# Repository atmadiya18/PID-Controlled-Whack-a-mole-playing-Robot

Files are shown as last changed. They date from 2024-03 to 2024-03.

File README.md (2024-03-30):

**PID Controlled Whack-a-mole playing robot** [_Jan 2022 - May2021_]
- Designed a "Whack-a-Mole" robot utilizing a PID control system for enhanced gameplay precision and interaction. Emphasized real-time responsiveness and dynamic strike        
  capabilities through meticulously calibrated control algorithms.
- Comprehensive Sensor Suite: Integrated a diverse array of sensors, including ultrasonic for distance measurement, an IMU for orientation and movement tracking, a line 
  follower sensor for precise path navigation, and an RGB color sensor for advanced target identification based on color differentiation.
- Engineered robot's mechanical structure using CATIA to optimize agility and efficiency. Employed servo motors for actuation, achieving rapid and precise movements, essential 
  for striking targets with high accuracy.
- Orchestrated complex operational logic using Arduino, effectively synthesizing sensor inputs with mechanical actions. Applied PID algorithms to fine-tune the robot's 
  movements and strikes, significantly reducing reaction times and increasing strike precision.
- Through strategic adjustments to the PID parameters and the integration of a holistic sensor approach, realized a 70% improvement in the robot's response time and a 45% 
  increase in accuracy. Demonstrated the robot's superior performance in adapting to game dynamics.
Project Impact and Innovation: The project exemplified the convergence of robotics, sensor technology, and control systems in creating interactive entertainment solutions. Set new benchmarks in automated game play, showcasing the potential for robotics in engaging and complex environments.

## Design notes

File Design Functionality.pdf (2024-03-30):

# DESIGN REQUIREMENTS AND CONSTRAINTS

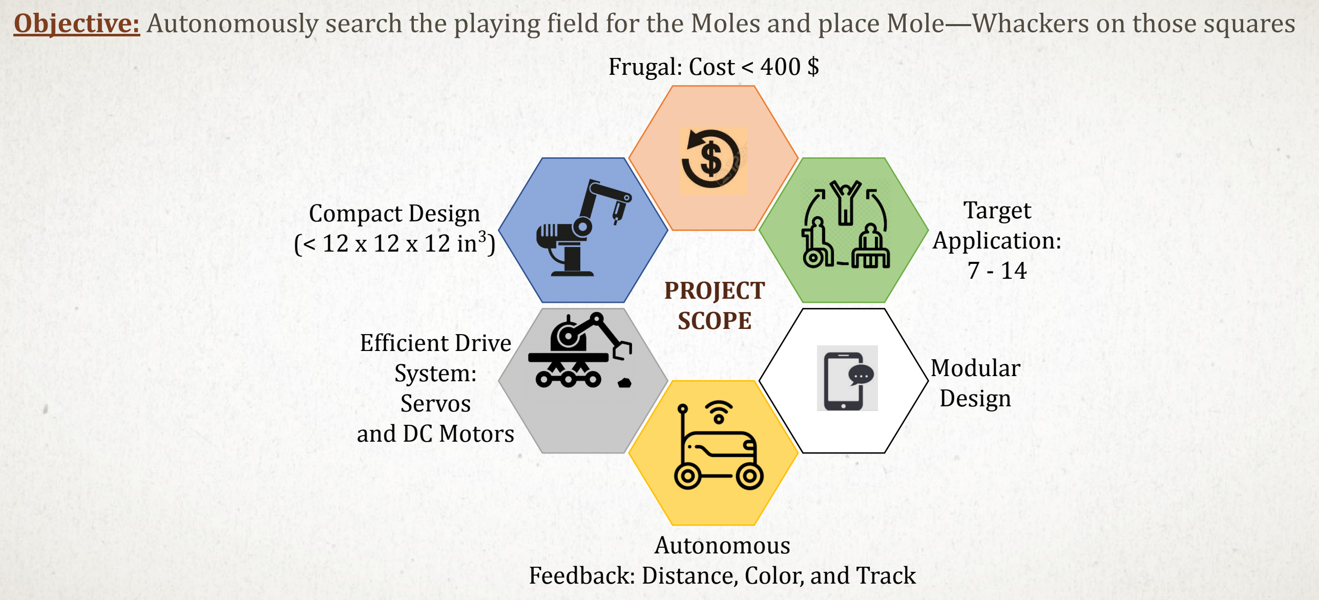
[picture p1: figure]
Frugal: Cost < 400 $; Target Application: 7 - 14; Modular Design; Compact Design (< 12 x 12 x 12 in³; Efficient Drive System: Servos and DC Motors; Autonomous Feedback: Distance, Color, and Track; PROJECT SCOPE

Objective: Autonomously search the playing field for the Moles and place Mole—Whackers on those squares

# DESIGN FUNCTIONALITY

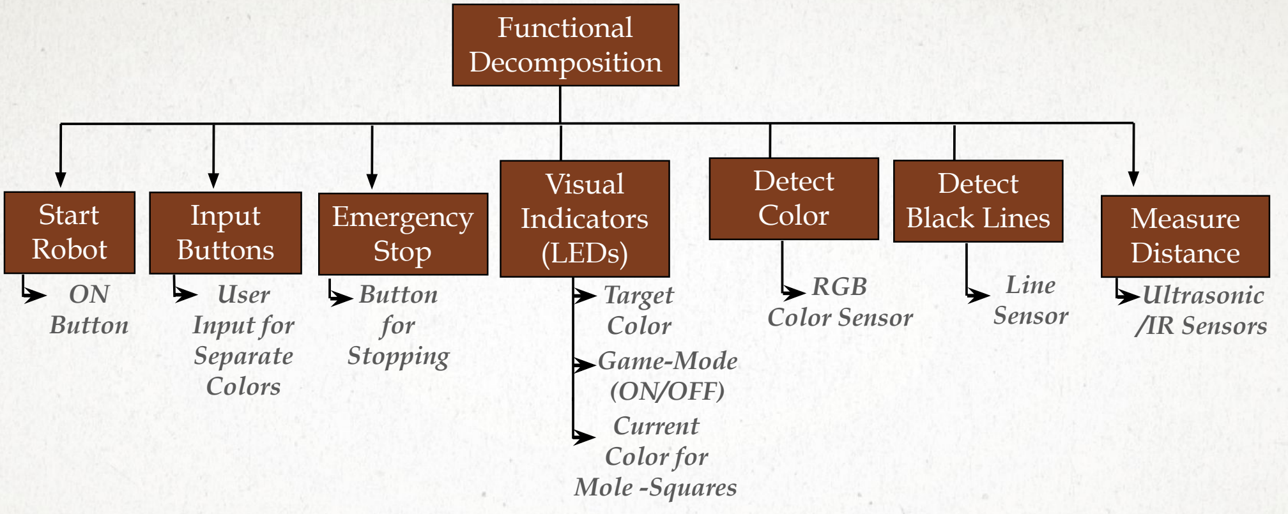
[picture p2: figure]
Start Robot; Measure Distance; Input Buttons; Emergency Stop; ON Button; User Input for Separate Colors; Button for Stopping; Ultrasonic /IR Sensors; Target Color; Functional Decomposition; Visual Indicators (LEDs); Game-Mode (ON/OFF) Current Color for Mole -Squares; RGB Color Sensor; Detect Color; Line Sensor; Detect Black Lines

# SYSTEMS ENGINEERING LAYOUT

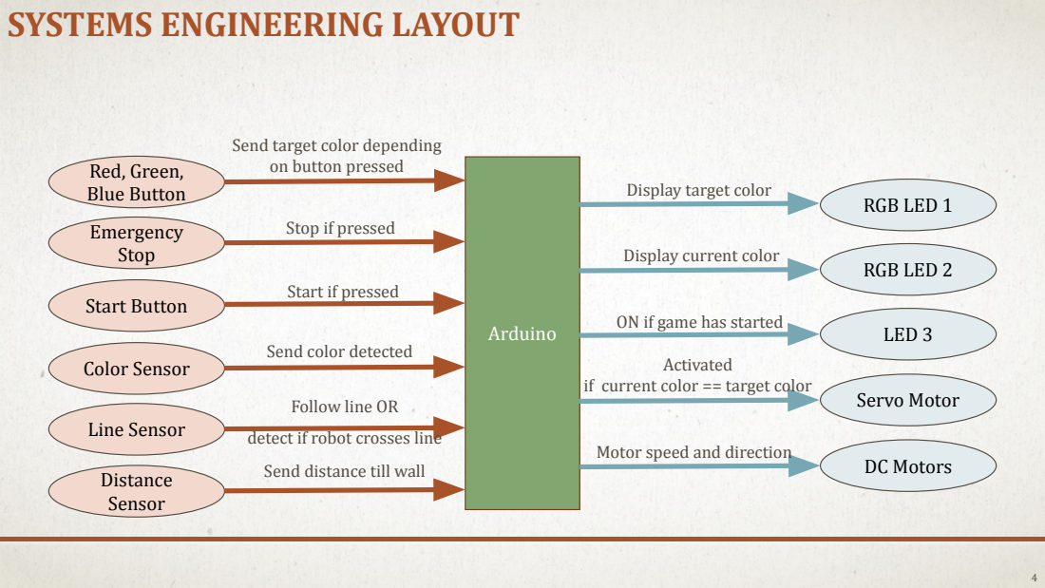
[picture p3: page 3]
Arduino; Red, Green, Blue Button; Emergency Stop; Start Button; Color Sensor; Line Sensor; RGB LED 1; RGB LED 2; LED 3; Servo Motor; DC Motors; Distance Sensor; Activated

Send target color depending
on button pressed

Display target color

Stop if pressed

Display current color

Start if pressed

ON if game has started

Send color detected

if current color == target color

Follow line OR
detect if robot crosses line

Motor speed and direction

Send distance till wall

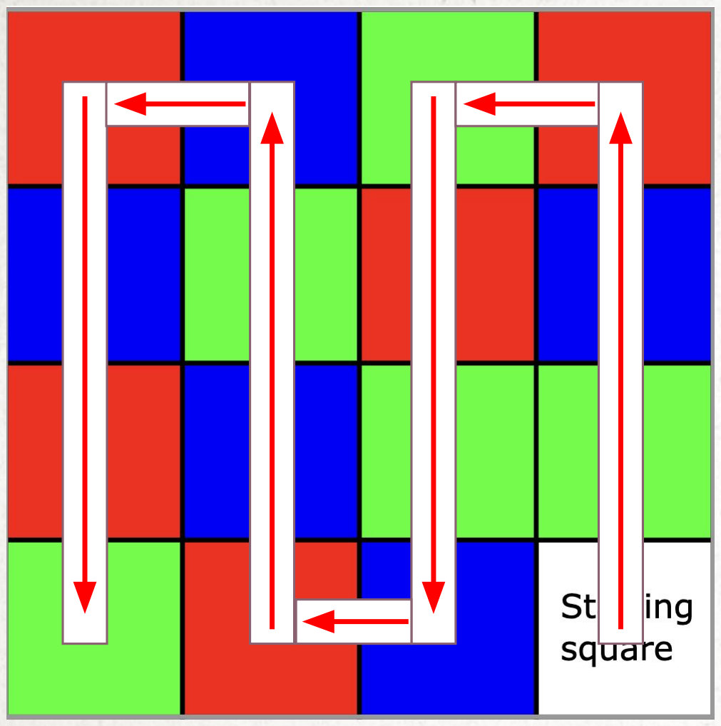
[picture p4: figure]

❑ Every Square Method
Robot follows the path given by the arrows to traverse every square
Based on the square under the robot: ball is dropped
This method might be the easiest to implement but could be slower

## STRATEGY: EVERY SQUARE METHOD

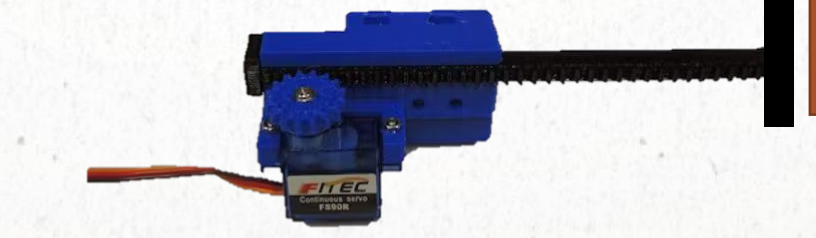
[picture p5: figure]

## STRATEGY: LINE FOLLOWER METHOD

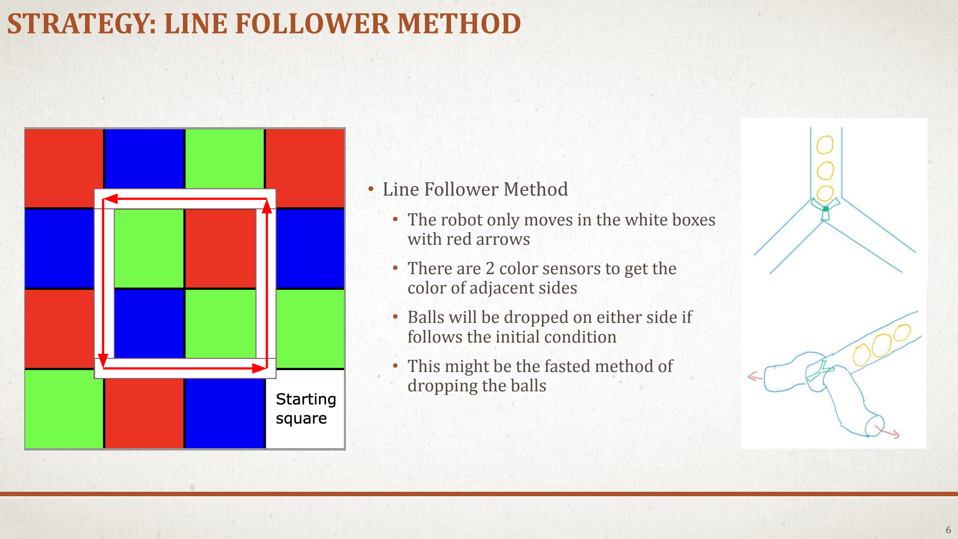
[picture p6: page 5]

- Line Follower Method
- The robot only moves in the white boxes with red arrows
- There are 2 color sensors to get the color of adjacent sides
- Balls will be dropped on either side if follows the initial condition
- This might be the fasted method of dropping the balls

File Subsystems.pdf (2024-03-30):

## MOVEMENT OF THE CHASSIS

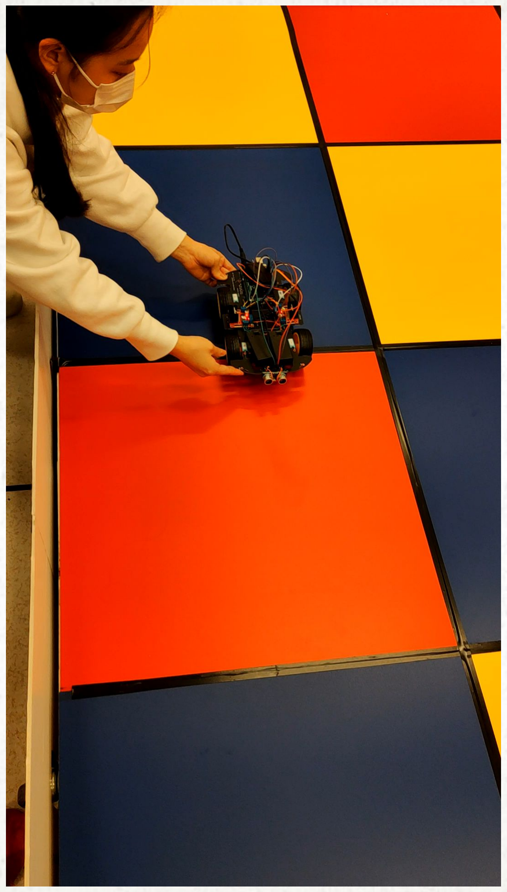
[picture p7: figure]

## MOLE-WHACKER DEPLOYMENT

- Servo motor horn attached to a structure with slots for mole-whacker to be deployed
- Range of motion of the servo horn (< 180 degrees) to deploy the mole-whacker
- Need for designing the mole-whacker deployer and servomotor to the chassis

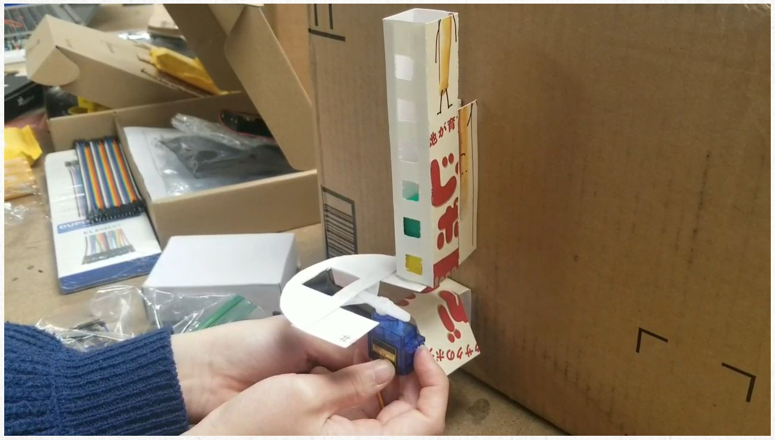
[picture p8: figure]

## SENSOR MODALITIES: ULTRASONIC SENSOR

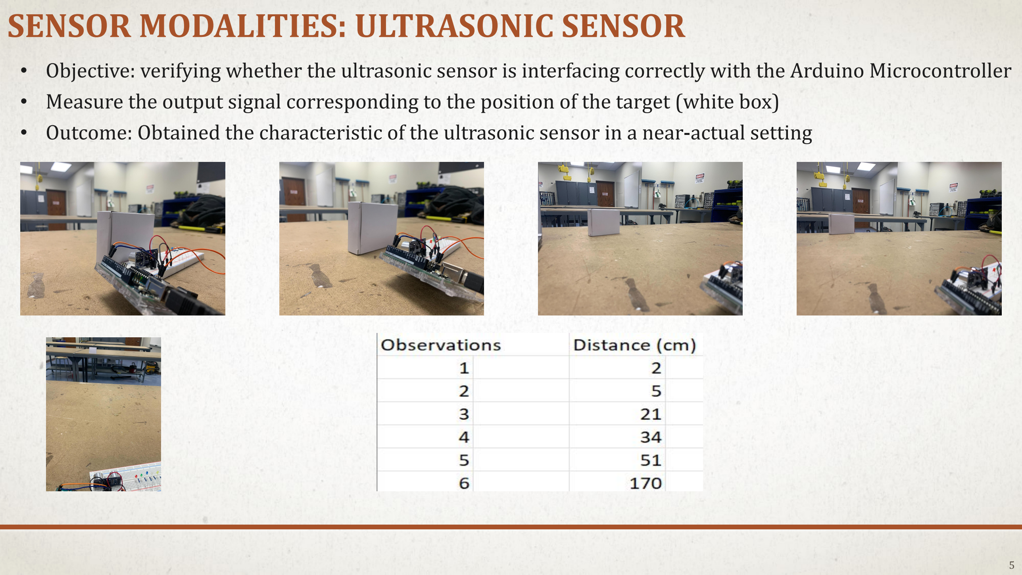
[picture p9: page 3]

- Objective: verifying whether the ultrasonic sensor is interfacing correctly with the Arduino Microcontroller
- Measure the output signal corresponding to the position of the target (white box)
- Outcome: Obtained the characteristic of the ultrasonic sensor in a near-actual setting

## SENSOR MODALITIES: LINE FOLLOWER

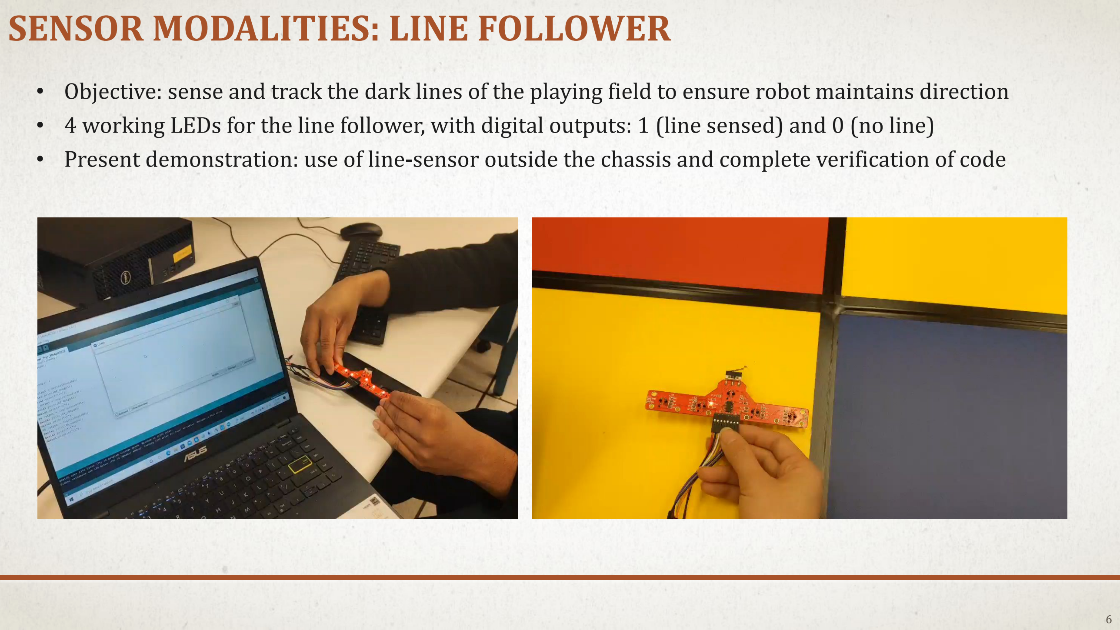
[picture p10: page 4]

- Objective: sense and track the dark lines of the playing field to ensure robot maintains direction
- 4 working LEDs for the line follower, with digital outputs: 1 (line sensed) and 0 (no line)
- Present demonstration: use of line-sensor outside the chassis and complete verification of code

## VISUAL INDICATOR

- R, Y, B LEDs for indicating target color
- Start LED for indicating the game has started (white)
- Green LED for indicating that the current square is the same as the target color

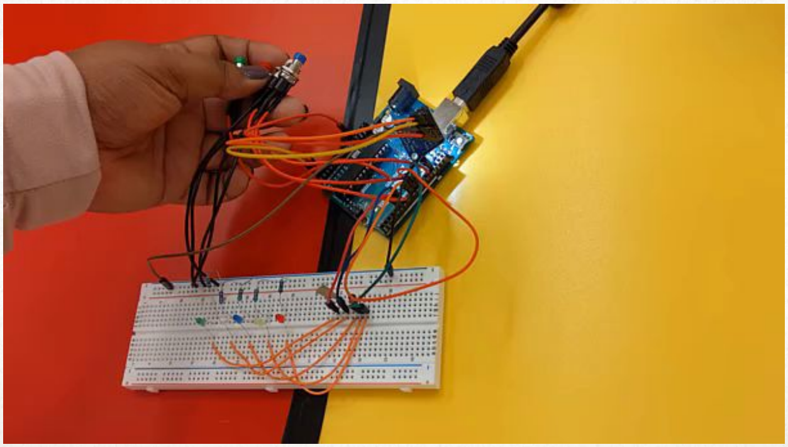
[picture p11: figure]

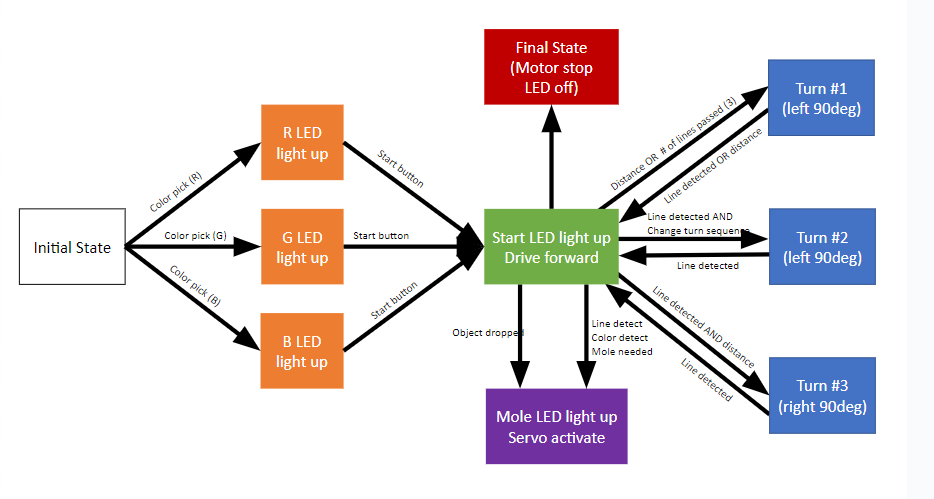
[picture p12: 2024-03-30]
FSM.png

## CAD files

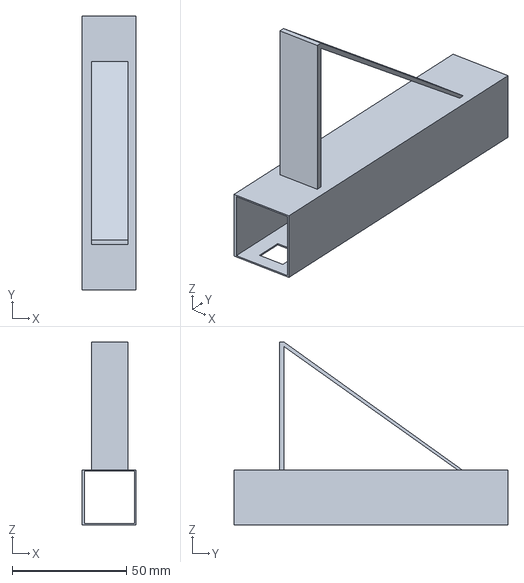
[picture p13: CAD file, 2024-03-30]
Whacker.igs
23.5 x 120.0 x 80.0 mm

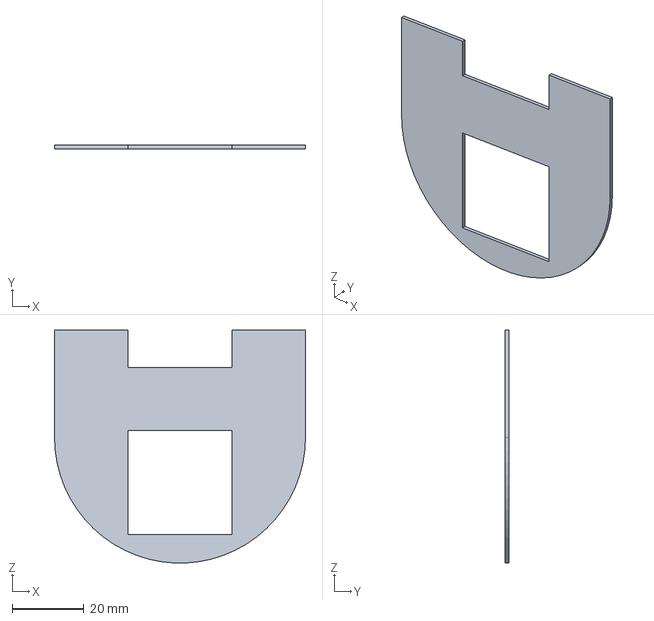
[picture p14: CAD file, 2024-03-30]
Stand.igs
70.0 x 1.00 x 65.0 mm

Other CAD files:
Whacker.CATPart
stand.CATPart

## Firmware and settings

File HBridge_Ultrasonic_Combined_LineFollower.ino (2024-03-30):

//driver mechanism
//I/O pins
//Motor 1
//PID constants

#define echoPin 50
#define trigPin 4

double kp = 2;
double ki = 5;
double kd = 1;

//First H Bridge

int en1 = 9; //Motor 1
int in1 = 7;
int in2 = 8;

int en2 = 3; //Motor 2
int in4 = 22;
int in3 = 24;

//Second H Bridge 
int en3 = 5; //Motor 3
int in5 = 12; // in1 of second H bridge
int in6 = 13; // in2 of second H bridge

int en4 = 6; //Motor 4 second H bridge
int in8 = 10; // in3 of second H Bridge
int in7 = 11; //in4 of second H Bridge 

// defines variables for Ultrasonic Sensor
long int duration; // variable for the duration of sound wave travel
int distance; // variable for the distance measurement
int measured_distance;

//Line Follower Output Check
int S2_check;
int S3_check;
int S4_check;
int S5_check;

int Linefollowerarray[5] = {0, 0, 0, 0, 0};

int linePassed = 0;

//for (int i = 0; i <= 3; i = i + 1) {
//  Linefollowerarray[i] = 0;
//}

//int in8 = ;//Define states
unsigned long currentTime, previousTime;
double elapsedTime;
double error;
double lastError;
double input, output, setPoint;
double cumError, rateError;

const int S2 = A2;
const int S3 = A3;
const int S4 = A4;
const int S5 = A5;

int S2_output;
int S3_output;
int S4_output;
int S5_output;

//const int STAGE_stop = 100;
//const int STAGE_forward = 101;
//const int STAGE_leftturn = 102;
//const int STAGE_rightturn = 103;
//int state = STAGE_stop;

void setup() {
  // put your setup code here, to run once:
  setPoint = 0;
  //set point at zero degrees; check from calibration of rotary encoder

  //Motor1
  pinMode(en1, OUTPUT);
  pinMode(in1, OUTPUT);
  pinMode(in2, OUTPUT);

  //Motor2
  pinMode(en2, OUTPUT);
  pinMode(in3, OUTPUT);
  pinMode(in4, OUTPUT);

  //Motor3
  pinMode(en3, OUTPUT);
  pinMode(in5, OUTPUT);
  pinMode(in6, OUTPUT);

  //Motor4
  pinMode(en4, OUTPUT);
  pinMode(in7, OUTPUT);
  pinMode(in8, OUTPUT);

  //Ultrasonic Sensor Pin Declarations
  pinMode(trigPin, OUTPUT); // Sets the trigPin as an OUTPUT
  pinMode(echoPin, INPUT); // Sets the echoPin as an INPUT
  Serial.begin(9600); // // Serial Communication is starting with 9600 of baudrate speed
  Serial.println("Ultrasonic Sensor HC-SR04 Test"); // print some text in Serial Monitor
  Serial.println("with Arduino UNO R3");

  //Line Follower Declaration

  pinMode(S2, INPUT);
  pinMode(S3, INPUT);
  pinMode(S4, INPUT);
  pinMode(S5, INPUT);
  // delay(3000);

}

void LineFollower(int Linefollowerarray[]) {

  S2_output = digitalRead(S2);
  Linefollowerarray[1] = S2_output;
  Serial.print(S2_output);
  Serial.print("\t");
  S3_output = digitalRead(S3);
  Linefollowerarray[2] = S3_output;
  Serial.print(S3_output);
  Serial.print("\t");
  S4_output = digitalRead(S4);
  Linefollowerarray[3] = S4_output;
  Serial.print(S4_output);
  Serial.print("\t");
  S5_output = digitalRead(S5);
  Linefollowerarray[4] = S5_output;
  Serial.print(S5_output);
  Serial.print("\t");
  Serial.println("\t");
}

double UltrasonicSensor()
{
  // Clears the trigPin condition
  digitalWrite(trigPin, LOW);
  delayMicroseconds(2);

  // Sets the trigPin HIGH (ACTIVE) for 10 microseconds
  digitalWrite(trigPin, HIGH);
  delayMicroseconds(10);
  digitalWrite(trigPin, LOW);

  // Reads the echoPin, returns the sound wave travel time in microseconds
  duration = pulseIn(echoPin, HIGH);
  // Calculating the distance
  distance = duration * 0.034 / 2; // Speed of sound wave divided by 2 (go and back)
  // Displays the distance on the Serial Monitor

  //  Serial.print("Distance: ");
  //  Serial.print(distance);
  //  Serial.println(" cm");

  return distance;
}

void loop() {
  // put your main code for direction here, to run repeatedly; this is for direction

  int measured_distance;
  measured_distance = UltrasonicSensor();
  LineFollower(Linefollowerarray);

  if (measured_distance > 30 && Linefollowerarray[2] == 1 && Linefollowerarray[3] == 0 && Linefollowerarray[4] == 1) {

    //S2 is 1; S3 is 2; S4 is 3; S5 is 4;
    //Serial.println(Linefollowerarray[3]);
    Serial.println("Going Straight");
    digitalWrite(in1, LOW); //Clockwise for Motor 1
    digitalWrite(in2, HIGH);
    analogWrite(en1, 160);

    digitalWrite(in3, HIGH); //clockwise for Motor 2
    digitalWrite(in4, LOW);
    analogWrite(en2, 160);

    digitalWrite(in5, LOW); // clockwise for Motor3
    digitalWrite(in6, HIGH);
    analogWrite(en3, 160);

    digitalWrite(in7, HIGH); // Clockwise for Motor4
    digitalWrite(in8, LOW);
    analogWrite(en4, 160);
  }

  else if (measured_distance > 30 && Linefollowerarray[2] == 1 && Linefollowerarray[3] == 1 && Linefollowerarray[4] == 0) {

    //S2 is 1; S3 is 2; S4 is 3; S5 is 4;
    //Serial.println(Linefollowerarray[4]);
    Serial.println("Going Left");

    digitalWrite(in1, LOW); //Clockwise for Motor 1
    digitalWrite(in2, HIGH);
    analogWrite(en1, 96);

    digitalWrite(in3, HIGH); //clockwise for Motor 2
    digitalWrite(in4, LOW);
    analogWrite(en2, 96);

    digitalWrite(in5, LOW); // clockwise for Motor3
    digitalWrite(in6, HIGH);
    analogWrite(en3, 160);

    digitalWrite(in7, HIGH); // Connections for Motor4
    digitalWrite(in8, LOW);
    analogWrite(en4, 160);
  }

  else if (measured_distance > 30 && Linefollowerarray[2] == 0 && Linefollowerarray[3] == 1 && Linefollowerarray[4] == 1) {

    //S2 is 1; S3 is 2; S4 is 3; S5 is 4;
    //Serial.println(Linefollowerarray[2]);
    Serial.println("Going Right");

    digitalWrite(in1, LOW); //Clockwise for Motor 1
    digitalWrite(in2, HIGH);
    analogWrite(en1, 160);

    digitalWrite(in3, HIGH); //clockwise for Motor 2
    digitalWrite(in4, LOW);
    analogWrite(en2, 160);

    digitalWrite(in5, LOW); // clockwise for Motor3
    digitalWrite(in6, HIGH);
    analogWrite(en3, 96);

    digitalWrite(in7, HIGH); // Connections for Motor4
    digitalWrite(in8, LOW);
    analogWrite(en4, 96);
  }

  else if (measured_distance > 30 && Linefollowerarray[2] == 0 && Linefollowerarray[3] == 0 && Linefollowerarray[4] == 0) {
    digitalWrite(in1, LOW); //Stop for Motor 1
    digitalWrite(in2, LOW);

    digitalWrite(in3, LOW); //Stop for Motor 2
    digitalWrite(in4, LOW);


    digitalWrite(in5, LOW); // Stop for Motor3
    digitalWrite(in6, LOW);


    digitalWrite(in7, LOW); // Stop for Motor4
    digitalWrite(in8, LOW);

    linePassed = linePassed + 1;

    delay(1000);
    if (linePassed == 3) {
      while (Linefollowerarray[4] == 1 && Linefollowerarray[3] == 1 && Linefollowerarray[1] == 1)
      {
        digitalWrite(in1, LOW); //Clockwise for Motor 1
        digitalWrite(in2, HIGH);
        analogWrite(en1, 224);

        digitalWrite(in3, LOW); //Anticlockwise for Motor 2
        digitalWrite(in4, HIGH);
        analogWrite(en2, 224);

        digitalWrite(in5, LOW); // clockwise for Motor3
        digitalWrite(in6, HIGH);
        analogWrite(en3, 224);

        digitalWrite(in7, LOW); // Anticlockwise for Motor4
        digitalWrite(in8, HIGH);
        analogWrite(en4, 224);

        delay(50);
      }
    }
    digitalWrite(in1, LOW); //Clockwise for Motor 1
    digitalWrite(in2,HIGH);
    analogWrite(en1, 160);

    digitalWrite(in3, HIGH); //clockwise for Motor 2
    digitalWrite(in4, LOW);
    analogWrite(en2, 160);

    digitalWrite(in5, LOW); // clockwise for Motor3
    digitalWrite(in6, HIGH);
    analogWrite(en3, 160);

    digitalWrite(in7, HIGH); // Clockwise for Motor4
    digitalWrite(in8, LOW);
    analogWrite(en4, 160);
  }
  
  else if (measured_distance < 30) {

    digitalWrite(in1, LOW); //Stop for Motor 1
    digitalWrite(in2, LOW);


    digitalWrite(in3, LOW); //Stop for Motor 2
    digitalWrite(in4, LOW);


    digitalWrite(in5, LOW); // Stop for Motor3
    digitalWrite(in6, LOW);


    digitalWrite(in7, LOW); // Stop for Motor4
    digitalWrite(in8, LOW);

    //additions for turing left

    delay(500);

    /*while (Linefollowerarray[4] == 1)
    {
      digitalWrite(in1, HIGH); //Clockwise for Motor 1
      digitalWrite(in2, LOW);
      analogWrite(en1, 160);

      digitalWrite(in3, HIGH); //Anticlockwise for Motor 2
      digitalWrite(in4, LOW);
      analogWrite(en2, 160);

      digitalWrite(in5, HIGH); // clockwise for Motor3
      digitalWrite(in6, LOW);
      analogWrite(en3, 224);

      digitalWrite(in7, HIGH); // Anticlockwise for Motor4
      digitalWrite(in8, LOW);
      analogWrite(en4, 224);

      delay(50);
    }
    */
  }
}

//delay (1000);
//}

double computePID(double inp, double kp, double ki, double kd){ //Only for PID Control
  
        currentTime = millis();                //get current time
        elapsedTime = (double)(currentTime - previousTime);        //compute time elapsed from previous computation

        error = Setpoint - inp;                                // determine error
        cumError += error * elapsedTime;                // compute integral
        rateError = (error - lastError)/elapsedTime;   // compute derivative

        double out = kp*error + ki*cumError + kd*rateError;                //PID output

        lastError = error;                                //remember current error
        previousTime = currentTime;                        //remember current time

        return out;                                        //have function return the PID output
}
